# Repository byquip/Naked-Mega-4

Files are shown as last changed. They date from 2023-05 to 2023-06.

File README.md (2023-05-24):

# Naked Mega 4
This is hardware design of Arduino Mega 2560 core. \
This design is based on Naked Mega \
designed by [Fuzzy Studio](https://github.com/FuzzyNoodle/Fuzzy-Naked-Mega) and [geraicerdas](https://github.com/geraicerdas/Cerdas-F2).

Tutorial [here](https://www.hackster.io/news/a-bare-naked-arduino-mega-2314647cf772)

This repo is an update of `geraicerdas` design to be more like Naked Mega 4.0 \
Instead of "Batik" design in the bottom Silkscreen as an Indonesian culture from `geraicerdas`. \
I added some vyshyvanka pattern as Ukrainian culture in the bottom Silkscreen which represent my hometown name Rubizhne in "Brodivsk" writing alphabet.

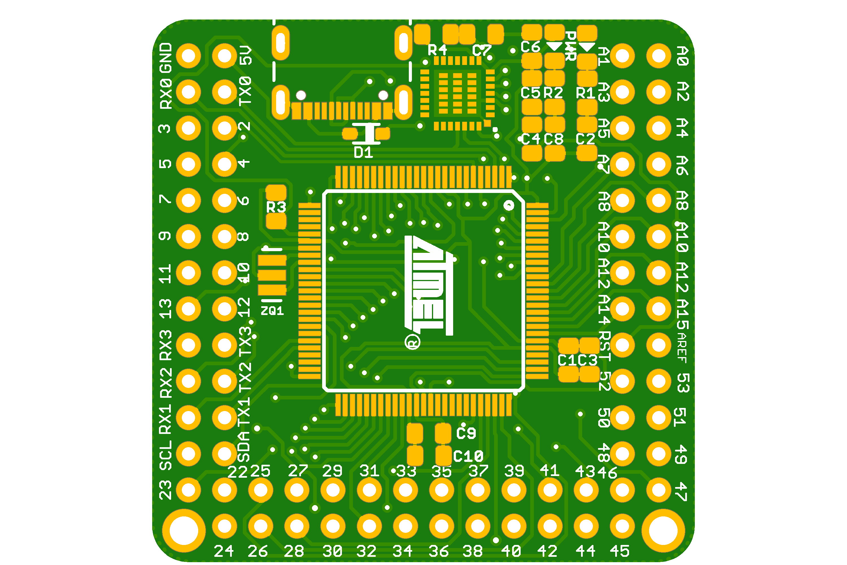
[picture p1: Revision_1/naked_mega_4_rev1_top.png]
top

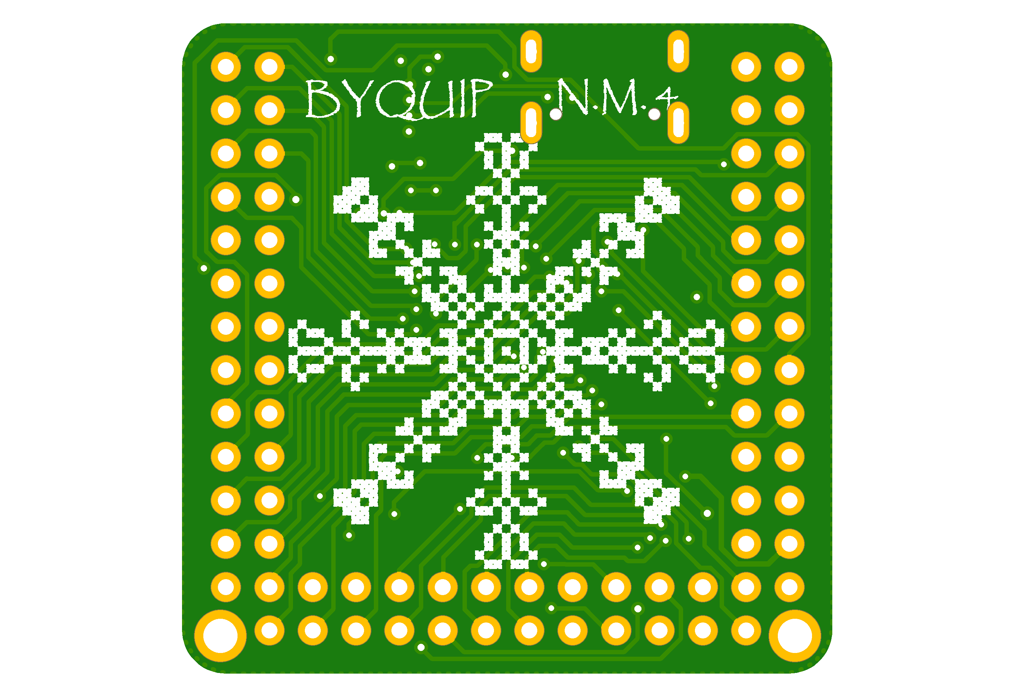
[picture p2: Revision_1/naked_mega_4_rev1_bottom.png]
bottom


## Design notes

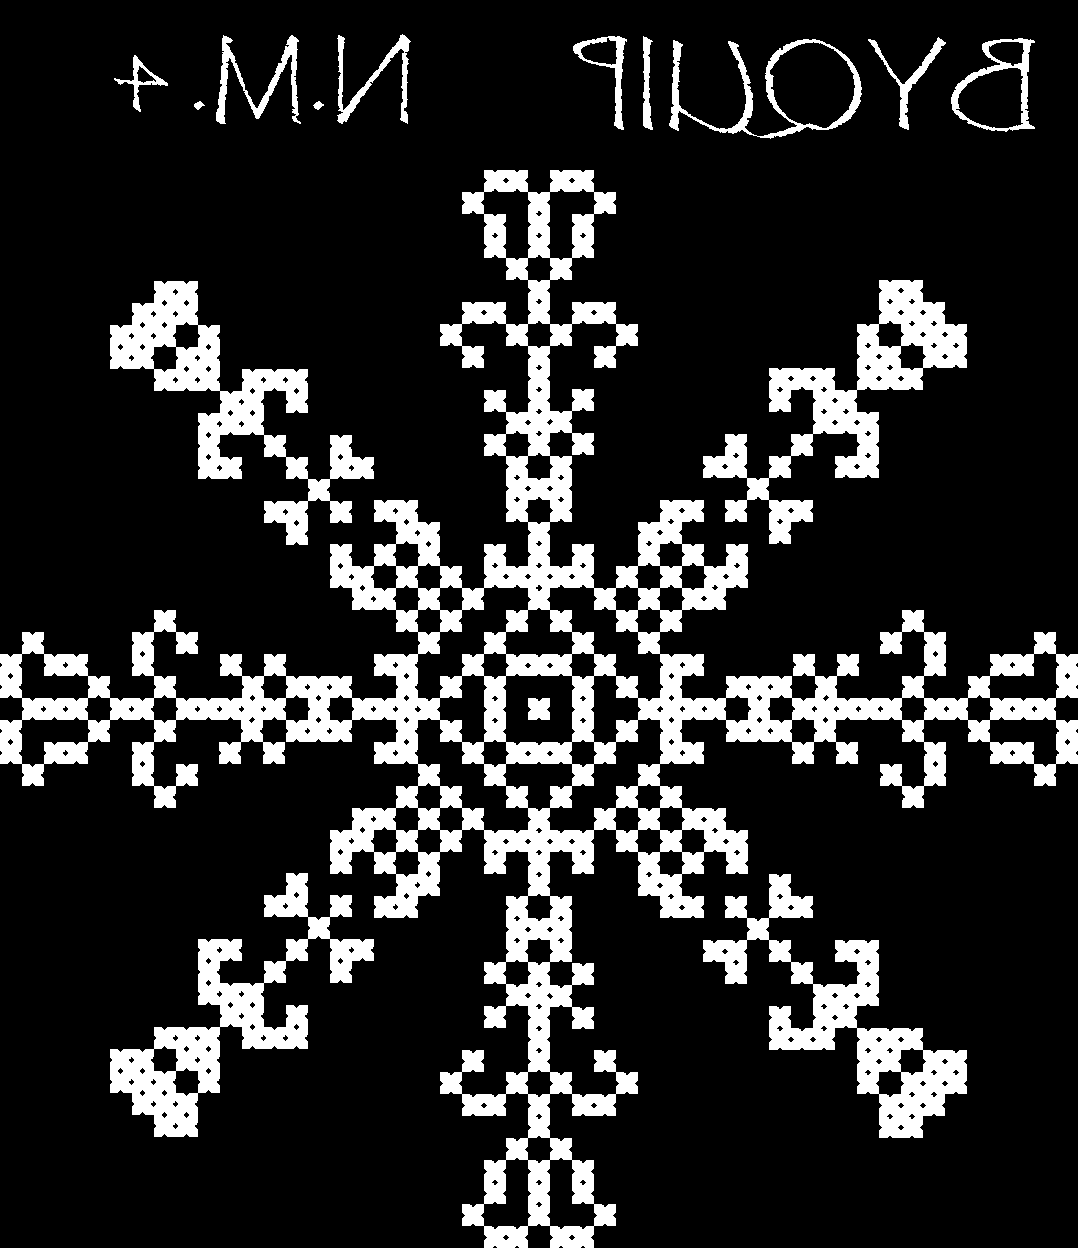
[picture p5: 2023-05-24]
Revision_1/rubizhne_silk_lay.bmp

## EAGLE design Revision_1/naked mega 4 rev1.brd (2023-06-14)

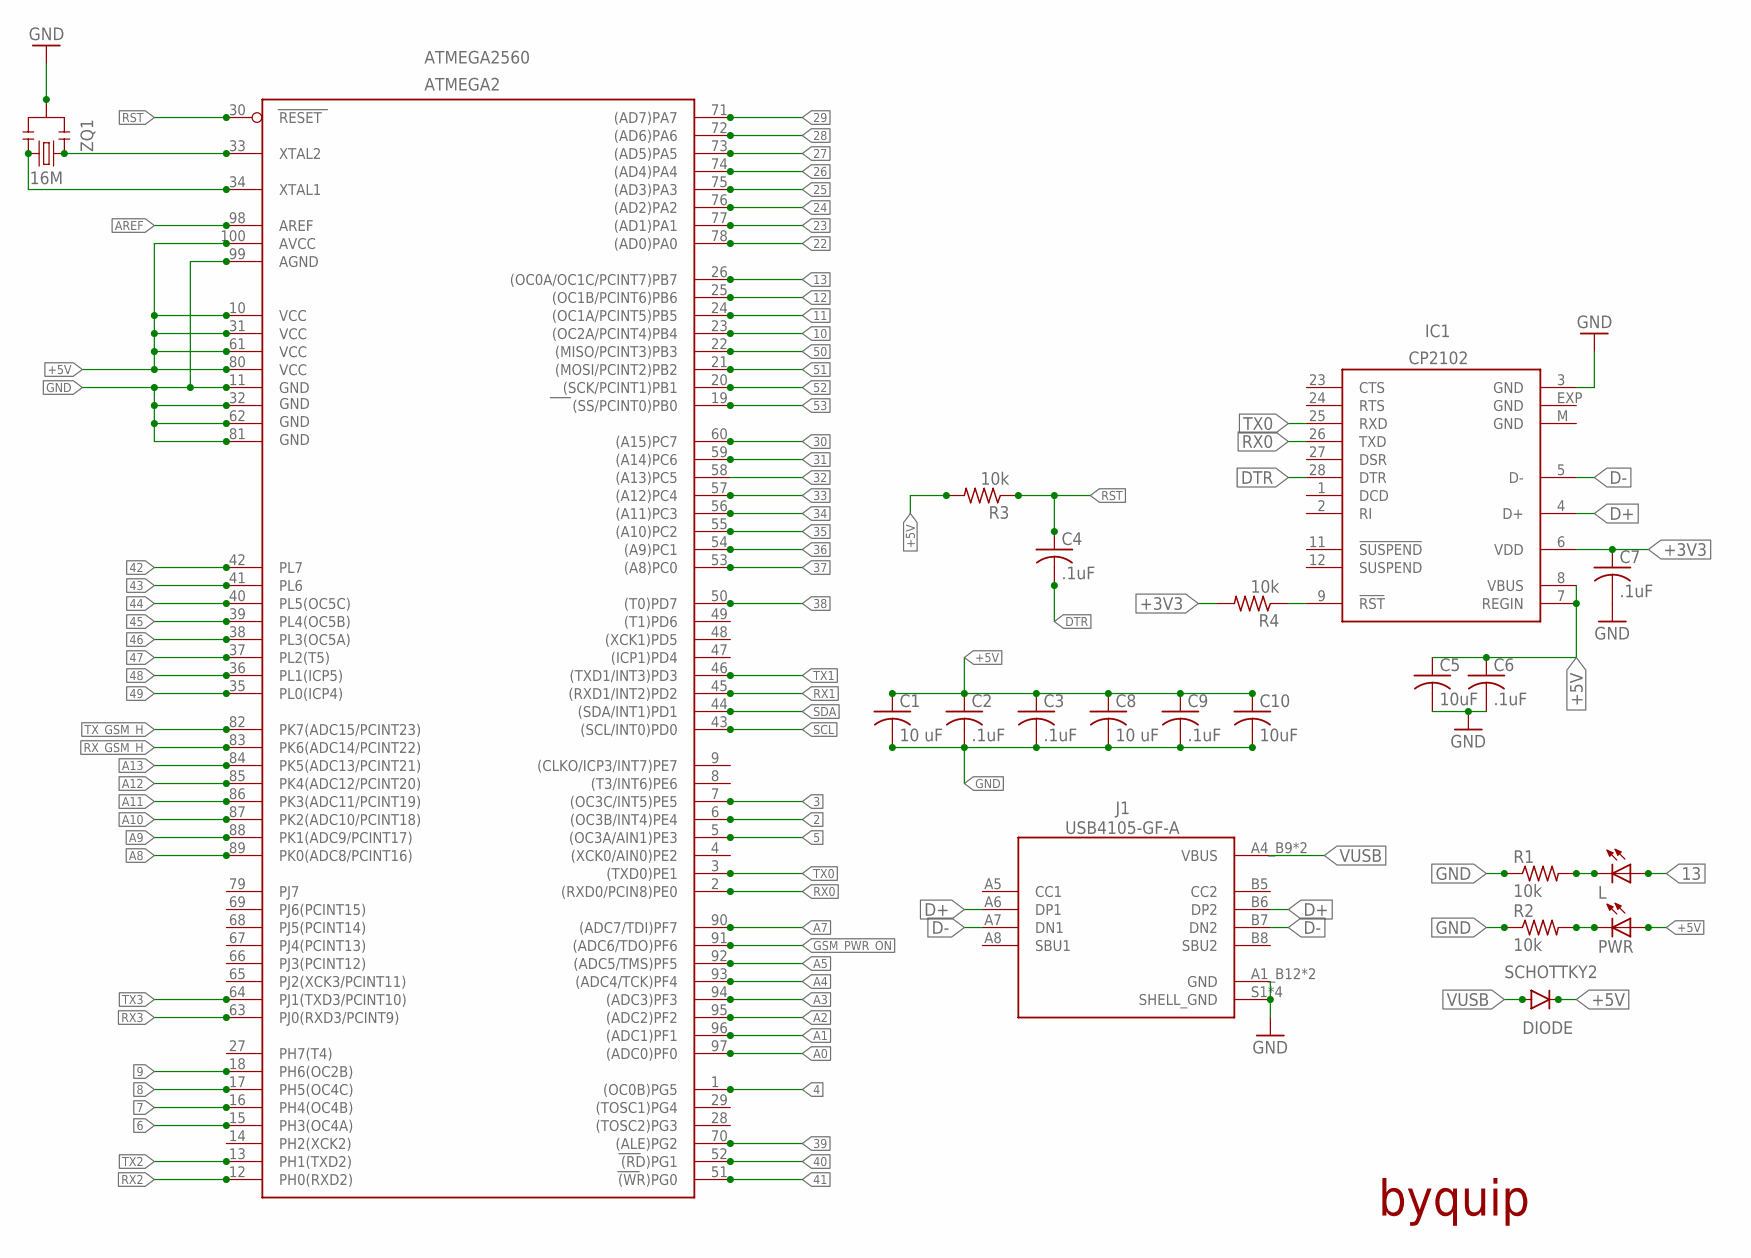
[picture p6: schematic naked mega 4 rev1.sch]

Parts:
ATMEGA2: ATMEGA2560; TQFP100
C1, C8: 10 uF; SMD-0805
C2, C3, C4, C6, C7, C9: .1uF; SMD-0805
C5, C10: 10uF; SMD-0805
IC1: CP2102; MLP28
J1: USB4105-GF-A; GCT_USB4105-GF-A
L: L; SMD-0805-LED
PWR: L; SMD-0805-LED
R1, R2, R3, R4: 10k; SMD-0805
SCHOTTKY2: DIODE; SOD-323
ZQ1: 16M; CSTCE*

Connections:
2: ATMEGA2.6 ((OC3B/INT4)PE4)
3: ATMEGA2.7 ((OC3C/INT5)PE5)
4: ATMEGA2.1 ((OC0B)PG5)
5: ATMEGA2.5 ((OC3A/AIN1)PE3)
6: ATMEGA2.15 (PH3(OC4A))
7: ATMEGA2.16 (PH4(OC4B))
8: ATMEGA2.17 (PH5(OC4C))
9: ATMEGA2.18 (PH6(OC2B))
10: ATMEGA2.23 ((OC2A/PCINT4)PB4)
11: ATMEGA2.24 ((OC1A/PCINT5)PB5)
12: ATMEGA2.25 ((OC1B/PCINT6)PB6)
13: ATMEGA2.26 ((OC0A/OC1C/PCINT7)PB7), L.1 (A)
22: ATMEGA2.78 ((AD0)PA0)
23: ATMEGA2.77 ((AD1)PA1)
24: ATMEGA2.76 ((AD2)PA2)
25: ATMEGA2.75 ((AD3)PA3)
26: ATMEGA2.74 ((AD4)PA4)
27: ATMEGA2.73 ((AD5)PA5)
28: ATMEGA2.72 ((AD6)PA6)
29: ATMEGA2.71 ((AD7)PA7)
30: ATMEGA2.60 ((A15)PC7)
31: ATMEGA2.59 ((A14)PC6)
32: ATMEGA2.58 ((A13)PC5)
33: ATMEGA2.57 ((A12)PC4)
34: ATMEGA2.56 ((A11)PC3)
35: ATMEGA2.55 ((A10)PC2)
36: ATMEGA2.54 ((A9)PC1)
37: ATMEGA2.53 ((A8)PC0)
38: ATMEGA2.50 ((T0)PD7)
39: ATMEGA2.70 ((ALE)PG2)
40: ATMEGA2.52 ((RD)PG1)
41: ATMEGA2.51 ((WR)PG0)
42: ATMEGA2.42 (PL7)
43: ATMEGA2.41 (PL6)
44: ATMEGA2.40 (PL5(OC5C))
45: ATMEGA2.39 (PL4(OC5B))
46: ATMEGA2.38 (PL3(OC5A))
47: ATMEGA2.37 (PL2(T5))
48: ATMEGA2.36 (PL1(ICP5))
49: ATMEGA2.35 (PL0(ICP4))
50: ATMEGA2.22 ((MISO/PCINT3)PB3)
51: ATMEGA2.21 ((MOSI/PCINT2)PB2)
52: ATMEGA2.20 ((SCK/PCINT1)PB1)
53: ATMEGA2.19 ((SS/PCINT0)PB0)
+3V3: C7.1, IC1.6 (VDD), R4.2
+5V: ATMEGA2.10 (VCC), ATMEGA2.31 (VCC1), ATMEGA2.61 (VCC2), ATMEGA2.80 (VCC3), ATMEGA2.100 (AVCC), C1.1, C2.1, C3.1, C5.1, C6.1, C8.1, C9.1, C10.1, IC1.7 (REGIN), IC1.8 (VBUS), PWR.1 (A), R3.2, SCHOTTKY2.C
A0: ATMEGA2.97 ((ADC0)PF0)
A1: ATMEGA2.96 ((ADC1)PF1)
A2: ATMEGA2.95 ((ADC2)PF2)
A3: ATMEGA2.94 ((ADC3)PF3)
A4: ATMEGA2.93 ((ADC4/TCK)PF4)
A5: ATMEGA2.92 ((ADC5/TMS)PF5)
A7: ATMEGA2.90 ((ADC7/TDI)PF7)
A8: ATMEGA2.89 (PK0(ADC8/PCINT16))
A9: ATMEGA2.88 (PK1(ADC9/PCINT17))
A10: ATMEGA2.87 (PK2(ADC10/PCINT18))
A11: ATMEGA2.86 (PK3(ADC11/PCINT19))
A12: ATMEGA2.85 (PK4(ADC12/PCINT20))
A13: ATMEGA2.84 (PK5(ADC13/PCINT21))
AREF: ATMEGA2.98 (AREF)
D+: IC1.4 (D+), J1.A6 (DP1), J1.B6 (DP2)
D-: IC1.5 (D-), J1.A7 (DN1), J1.B7 (DN2)
DTR: C4.2, IC1.28 (DTR)
GND: ATMEGA2.11 (GND), ATMEGA2.32 (GND1), ATMEGA2.62 (GND2), ATMEGA2.81 (GND3), ATMEGA2.99 (AGND), C1.2, C2.2, C3.2, C5.2, C6.2, C7.2, C8.2, C9.2, C10.2, IC1.3 (GND), IC1.EXP (GND), IC1.M (GND), J1.A1_B12 (GND), J1.B1_A12 (GND), J1.S1 (SHELL_GND), J1.S2 (SHELL_GND), J1.S3 (SHELL_GND), J1.S4 (SHELL_GND), R1.1, R2.1, ZQ1.2
GSM_PWR_ON: ATMEGA2.91 ((ADC6/TDO)PF6)
unnamed: ATMEGA2.34 (XTAL1), ZQ1.3
unnamed: ATMEGA2.33 (XTAL2), ZQ1.1
unnamed: L.2 (C), R1.2
unnamed: IC1.9 (!RST), R4.1
unnamed: PWR.2 (C), R2.2
RST: ATMEGA2.30 (RESET), C4.1, R3.1
RX0: ATMEGA2.2 ((RXD0/PCIN8)PE0), IC1.26 (TXD)
RX1: ATMEGA2.45 ((RXD1/INT2)PD2)
RX2: ATMEGA2.12 (PH0(RXD2))
RX3: ATMEGA2.63 (PJ0(RXD3/PCINT9))
RX_GSM_H: ATMEGA2.83 (PK6(ADC14/PCINT22))
SCL: ATMEGA2.43 ((SCL/INT0)PD0)
SDA: ATMEGA2.44 ((SDA/INT1)PD1)
TX0: ATMEGA2.3 ((TXD0)PE1), IC1.25 (RXD)
TX1: ATMEGA2.46 ((TXD1/INT3)PD3)
TX2: ATMEGA2.13 (PH1(TXD2))
TX3: ATMEGA2.64 (PJ1(TXD3/PCINT10))
TX_GSM_H: ATMEGA2.82 (PK7(ADC15/PCINT23))
VUSB: J1.A4_B9 (VBUS), J1.B4_A9 (VBUS), SCHOTTKY2.A

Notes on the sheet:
byquip

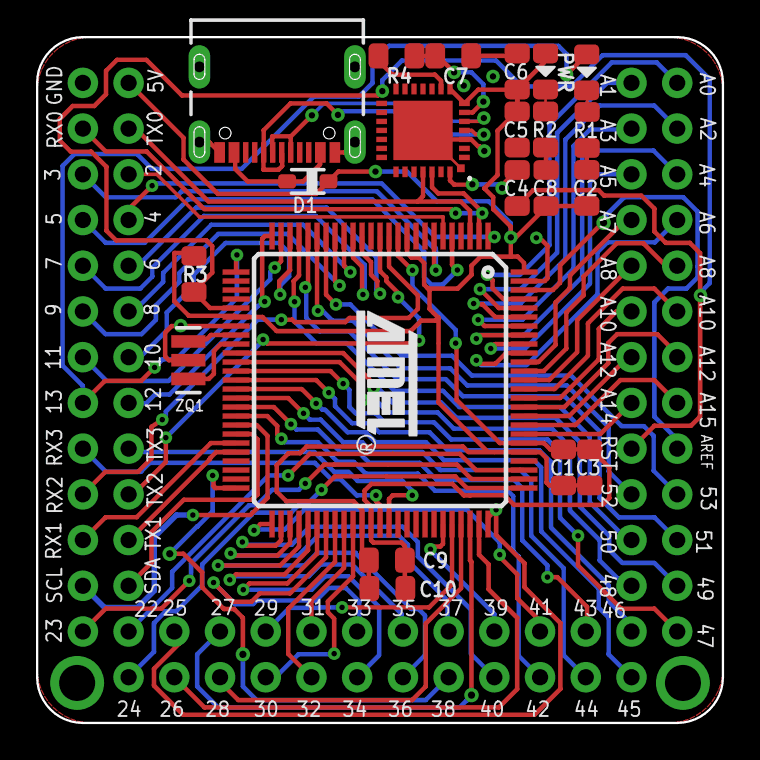
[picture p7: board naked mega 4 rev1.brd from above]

Board: 2 copper layers, 38.1 x 38.1 mm, 22 parts (0 on the bottom side), 16 nets.

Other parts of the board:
U$4: RUBIZHNE-VYSHYVANKA-LOGO

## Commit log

2023-05-24 link fix
    [naked mega 4 rev1.brd, naked mega 4 rev1.sch]
2023-06-14 fixed wrong tx/rx connection
    [naked mega 4 rev1.brd, naked mega 4 rev1.sch]
2023-06-14 silk lay finetuning
    [naked mega 4 rev1.brd]
2023-06-15 added gerber for jlcpcb
